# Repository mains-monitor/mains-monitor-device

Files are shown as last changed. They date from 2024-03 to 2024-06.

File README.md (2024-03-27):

# Mains Monitor

The device monitors a presence of mains voltage and sends notifications to the Backend when it turns on or off.
It uses ESP32-C3 MCU as a core component. It implements the logic of the device and connects it to the outer world via Wi-Fi.

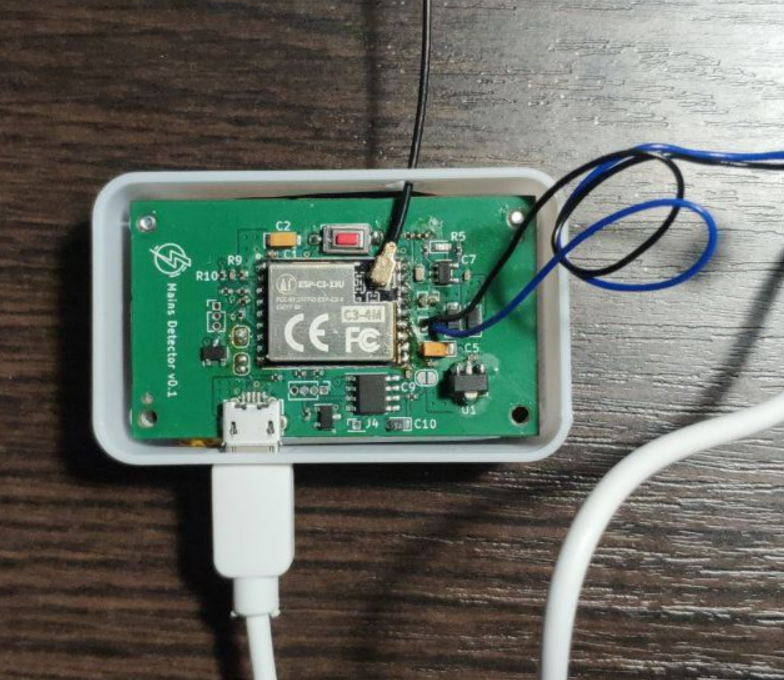
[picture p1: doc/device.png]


The device powers from 5V DC via micro-USB connector and from 3.7V 1000 mAh Li-Po battery, when mains is not available.
Most of the time the device stays in deep sleep mode, so it consumes micro Amps. It wakes up for 20 sec when 5V DC power source becomes available or turns off just for sending a notification to the Backend, then goes to deep sleep again. Peak power consumption when device is transmitting data via Wi-Fi is 500 mA.

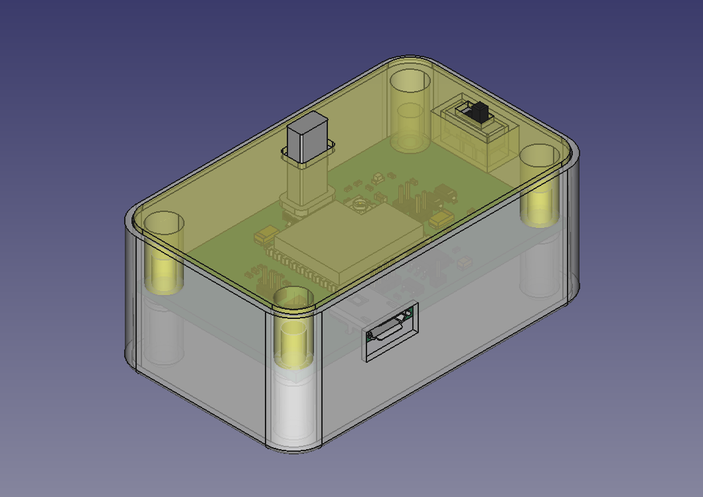
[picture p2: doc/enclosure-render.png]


# First launch configuration

When device starts the first time it creates a Wi-Fi hotspot network with SSID ``MD_<CHIPID>``. The password is ``md123456``.
Connect to it from a smartphone. After that it will open a configuration portal powered by WiFiManager Arduino library. It allows you to select a home Wi-Fi network the device will be connected to and a DTEK group number. The DTEK group number will be used later on the Backend.

# Folders & files description

* ``cad/`` - FreeCAD project and *.STL files of the enclosure for 3D printing
* ``libs/`` - KiCAD library files (schematic symbols and footprints)
* ``production/`` - Gerber, component placement files and Bill Of Materials for PCB production on the factory (for example, JLCPCB)
* ``firmware/`` - firmware sources for ESP32-C3 MCU, the heart of Mains Monitor

# Schematic

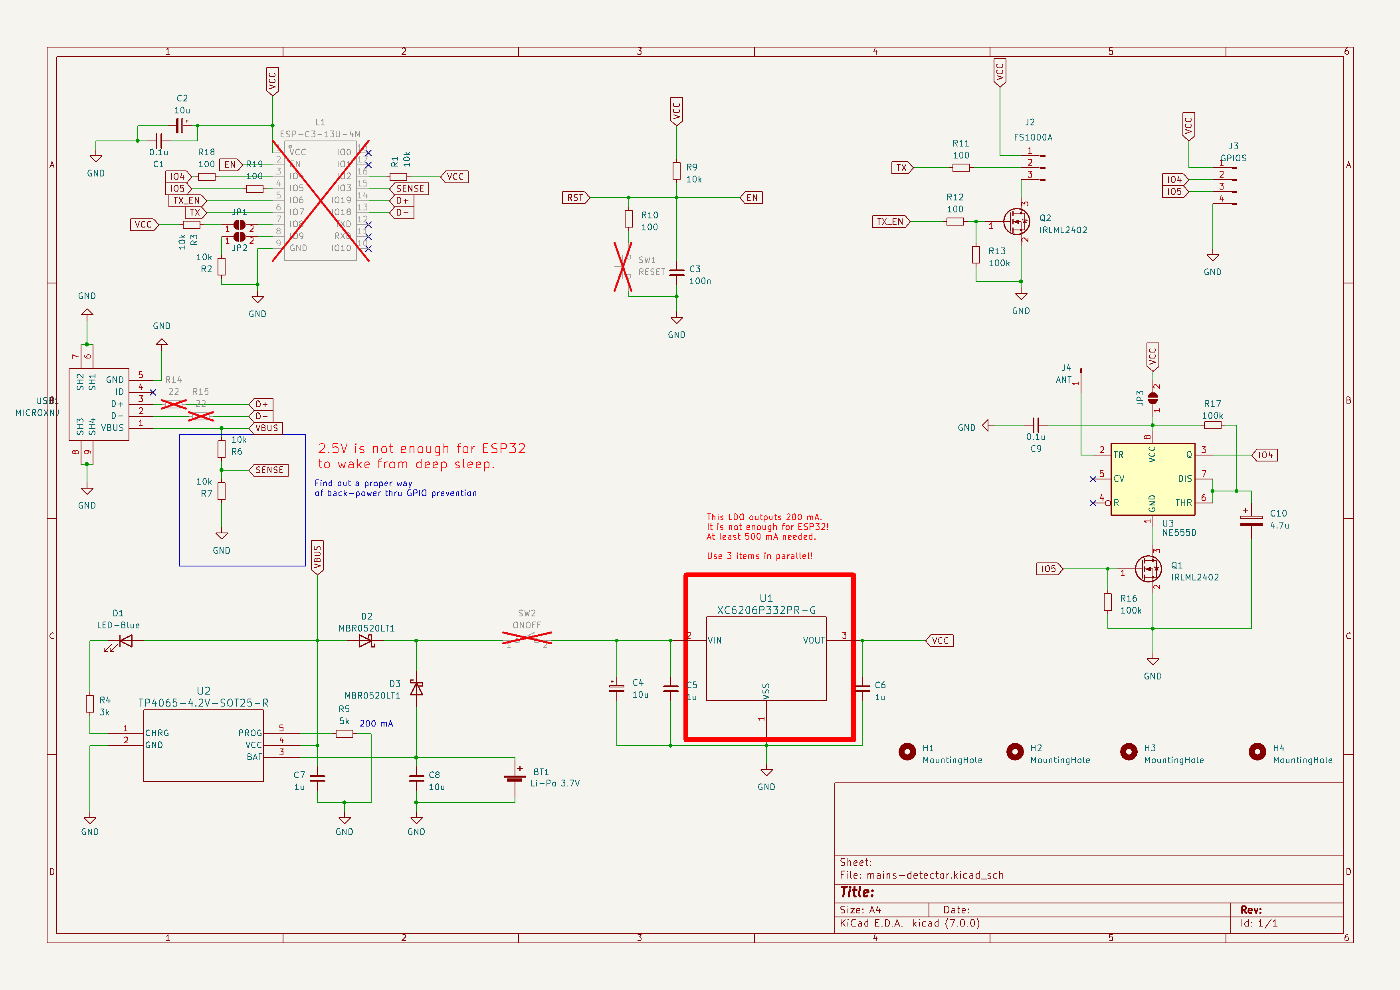
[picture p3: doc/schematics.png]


## PCB design

See [PDF file](doc/pcb-design.pdf) or ``./mains-detector.kicad_pcb`` filer in KiCAD format.

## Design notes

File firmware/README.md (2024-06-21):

# Mains Monitor firmware

* Uses Arduino library
* Uses WiFiManager for first configuration of the device

## How to build and upload firmware

1. Copy and rename ``env.example`` to ``.env``
1. Provide the actual values for environment variables, for example

        MD_API_ENDPOINT_HOST=api.example.server.com
        MD_API_ENDPOINT_PATH=/mains-monitor/set-state
1. Open the project in VSCode with Platformio extension installed and build it
1. Connect the device to a laptop or PC via USB, it will appear as a COM port on Windows
1. Configure Platformio to use that COM port
1. Click "Platformio: Upload" and click reset button on the device to wake it up. Note, the device will be active for 20s and then will disconnect from USB. You have to start flashing it within this interval.

## How to dump nvs partition and read its values on PC

1. Read partition table first, to see where is ``nvs`` partition is located

        esptool -p <COM_PORT OR TTY DEV> read_flash 0x8000 0x1000 part_table.bin

2. Decode partition table with ``gen_esp32part.py``, so you know the partition offset and size of ``nvs``

        python gen_esp32part.py part_table.bin

You should get output like the following:

        Parsing binary partition input...
        Verifying table...
        # ESP-IDF Partition Table
        # Name, Type, SubType, Offset, Size, Flags
        nvs,data,nvs,0x9000,24K,
        phy_init,data,phy,0xf000,4K,
        factory,app,factory,0x10000,1M,
        storage,data,spiffs,0x110000,960K,

3. Read ``nvs`` partition data using ``esptool``

        esptool -p <COM_PORT OR TTY DEV> read_flash 0x9000 0x6000 nvs_readout.bin

``0x6000`` is 24K in HEX

4. Decode ``nvs`` binary

        python analyze_nvs.py nvs_readout.bin -s -b 32

## How to erase ``nvs`` to reset the settings

        python parttool.py -p <COM_PORT OR TTY DEV> erase_partition --partition-name nvs

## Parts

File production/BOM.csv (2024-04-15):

Comment | Designator | Footprint | LCSC
0.1u | C1,C9 | Capacitor_SMD:C_0402_1005Metric | C307331
10u | C2,C4 | Capacitor_Tantalum_SMD:CP_EIA-3216-10_Kemet-I_Pad1.58x1.35mm_HandSolder | C7171
100n | C3 | Capacitor_SMD:C_0402_1005Metric | C307331
1u | C5,C6,C7,C11,C12 | Capacitor_SMD:C_0402_1005Metric | C52923
10u | C8 | Capacitor_SMD:C_0603_1608Metric | C96446
4.7u | C10 | Capacitor_Tantalum_SMD:CP_EIA-2012-12_Kemet-R | C2158112
LED-Blue | D1 | LED_SMD:LED_0603_1608Metric | C2286
MBR0520LT1 | D2,D3 | Diode_SMD:D_SOD-123 | C8598
STATUS | D4 | LED_SMD:LED_0603_1608Metric | C2290
IRLML2402 | Q1,Q2 | Package_TO_SOT_SMD:SOT-23 | C20917
10k | R1,R2,R3,R7,R9 | Resistor_SMD:R_0402_1005Metric | C25744
3k | R4,R8 | Resistor_SMD:R_0402_1005Metric | C25784
5k | R5,R6 | Resistor_SMD:R_0402_1005Metric | C25905
100 | R10,R11,R12,R18,R19 | Resistor_SMD:R_0402_1005Metric | C25076
100k | R13,R16,R17 | Resistor_SMD:R_0402_1005Metric | C25741
XC6206P332PR-G | U1,U4,U5 | footprints:SOT-89_TOR | C526275
TP4065-4.2V-SOT25-R | U2 | footprints1:SOT-23-5L_TPW | C113540
NE555D | U3 | Package_SO:SOIC-8_3.9x4.9mm_P1.27mm | C356725
MICROXNJ | USB1 | kicad_lceda:MICRO-USB-SMD_MICROXNJ | C404969

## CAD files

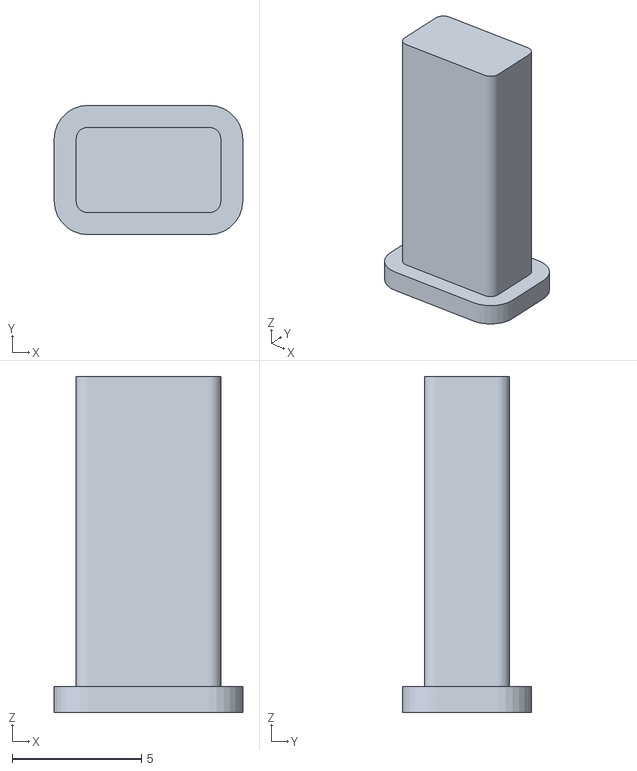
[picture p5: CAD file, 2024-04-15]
cad/enclosure-AssemblyResetButton.stl
7.30 x 5.00 x 13.0

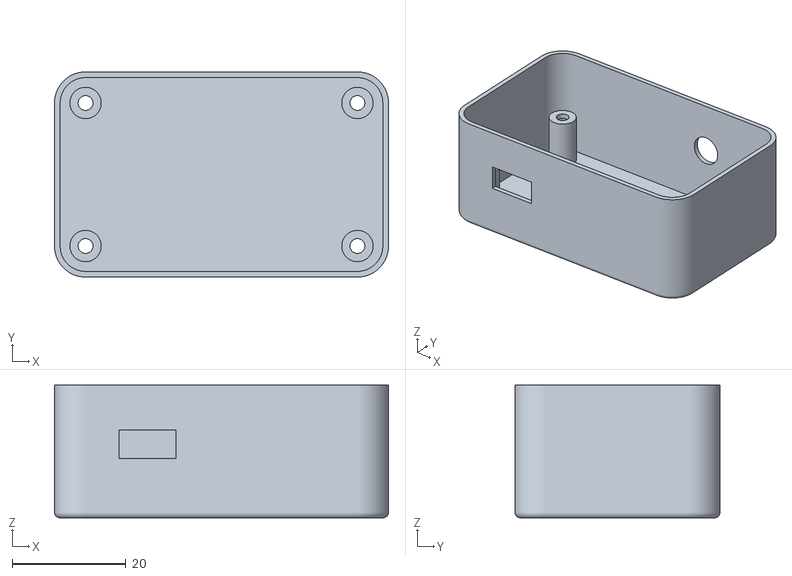
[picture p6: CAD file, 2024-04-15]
cad/enclosure-AssemblyBottomPart.stl
58.6 x 36.0 x 23.3

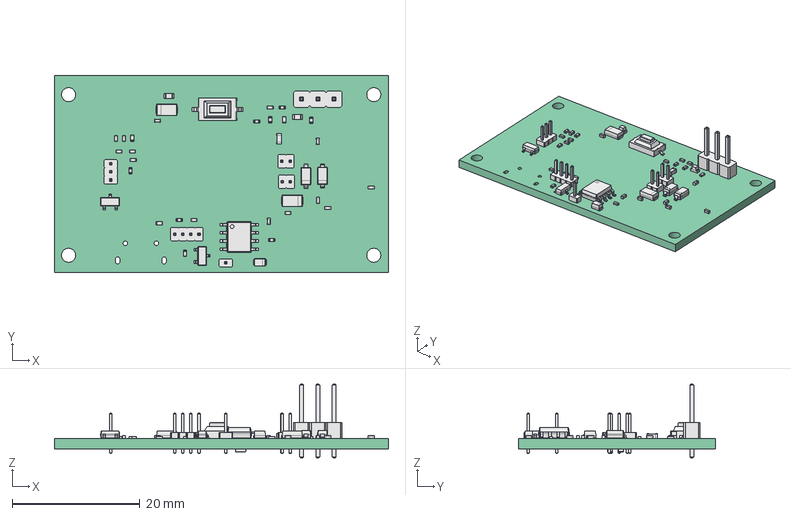
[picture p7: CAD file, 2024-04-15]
cad/mains-detector-tmp.FCStd
52.2 x 30.8 x 11.5 mm
Pcb_dab4
${REFERENCE}_C_0402_1005Metric_null x 8
${REFERENCE}_R_0402_1005Metric_null x 17
${REFERENCE}_PinHeader_1x03_P254mm_Vertical_null
${REFERENCE}_SOIC_8_39x49mm_P127mm_null
${REFERENCE}_LED_0603_1608Metric_null x 2
${REFERENCE}_SOT_23_null x 2
${REFERENCE}_C_0603_1608Metric_null
${REFERENCE}_PinHeader_1x04_P127mm_Vertical_null
${REFERENCE}_PinHeader_1x01_P127mm_Vertical_null
${REFERENCE}_PinHeader_1x03_P127mm_Vertical_null
${REFERENCE}_PinHeader_1x02_P127mm_Vertical_null x 2
${REFERENCE}_CP_EIA_2012_12_Kemet_R_null
${REFERENCE}_CP_EIA_3216_10_Kemet_I_null x 2
${REFERENCE}_D_SOD_123_null x 2
${REFERENCE}_SW_SPST_CK_RS282G05A3_null
${REFERENCE}_R_0603_1608Metric_null x 2

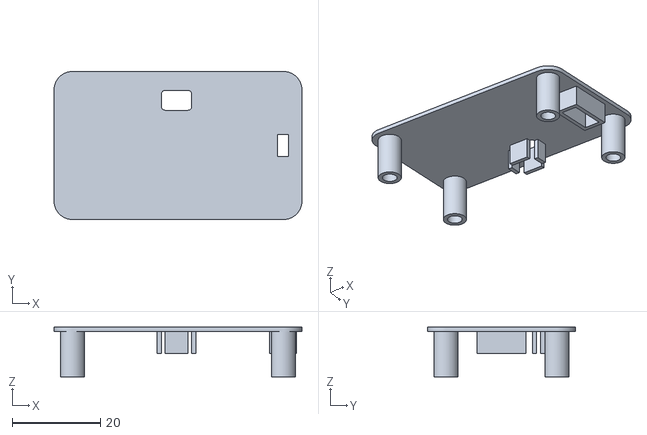
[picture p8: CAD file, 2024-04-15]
cad/enclosure-AssemblyTopPart.stl
56.1 x 33.5 x 11.3

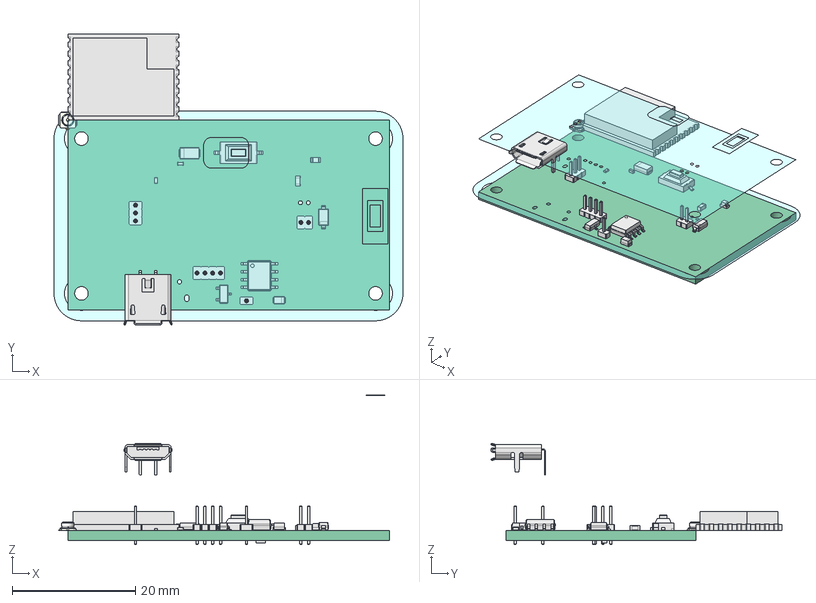
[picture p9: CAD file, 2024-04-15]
cad/enclosure.FCStd
56.6 x 47.3 x 24.2 mm
PinGND
PinSign
PinGND001
Micro USB 2 pin
Pcb_dab4
C1_C_0402_1005Metric_6f217ad45a18
R9_R_0402_1005Metric_7eab74a2859a
U3_SOIC_8_39x49mm_P127mm_bba1476a081f
D1_LED_0603_1608Metric_7d91a2106a29
Q1_SOT_23_2e7f4aaea85a
C8_C_0603_1608Metric_5c3886aaa098
J3_PinHeader_1x04_P127mm_Vertical_1c922c4ce59d
J4_PinHeader_1x01_P127mm_Vertical_20e830154123
J2_PinHeader_1x03_P127mm_Vertical_7fb6fa2eeee2
SW2_PinHeader_1x02_P127mm_Vertical_0a334a59d262
C10_CP_EIA_2012_12_Kemet_R_8c60f9f2d0d4
C2_CP_EIA_3216_10_Kemet_I_f65035e6d3dc
D3_D_SOD_123_7fc438e2cfe4
SW1_SW_SPST_CK_RS282G05A3_fa16e5ecf222
R14_R_0603_1608Metric_df99ae290d1b
_Element
_Element005
_Element006
_Element007
_Element008
_Element009
_Element010

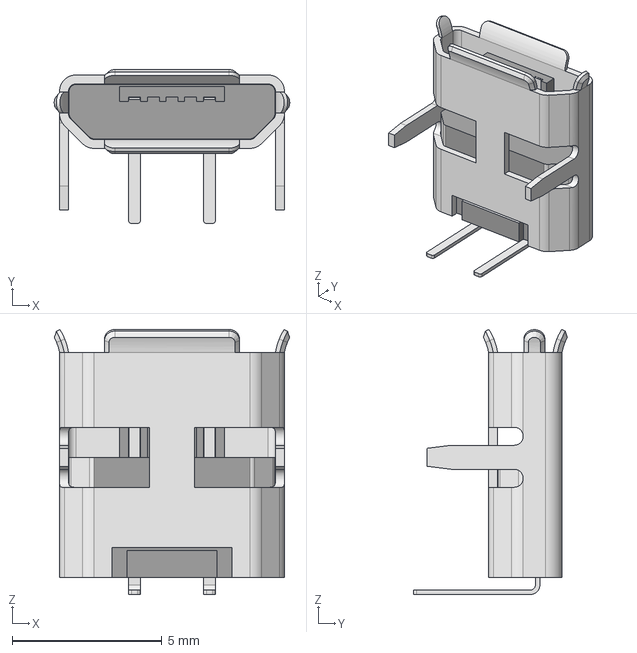
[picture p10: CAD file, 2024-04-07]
cad/Micro USB 2 pin.step
7.85 x 5.13 x 8.83 mm

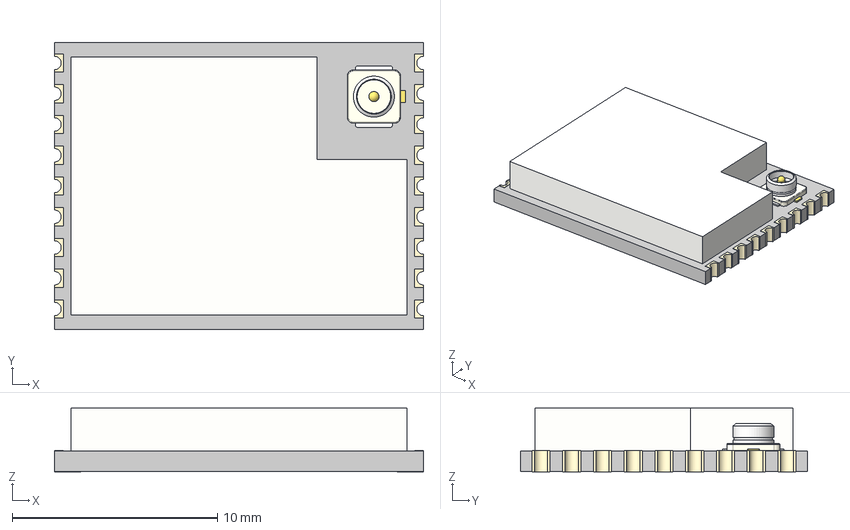
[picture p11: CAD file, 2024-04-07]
cad/ESP32-C3-13U v2.step
18.0 x 14.0 x 3.12 mm
PinGND
PinSign
PinGND001

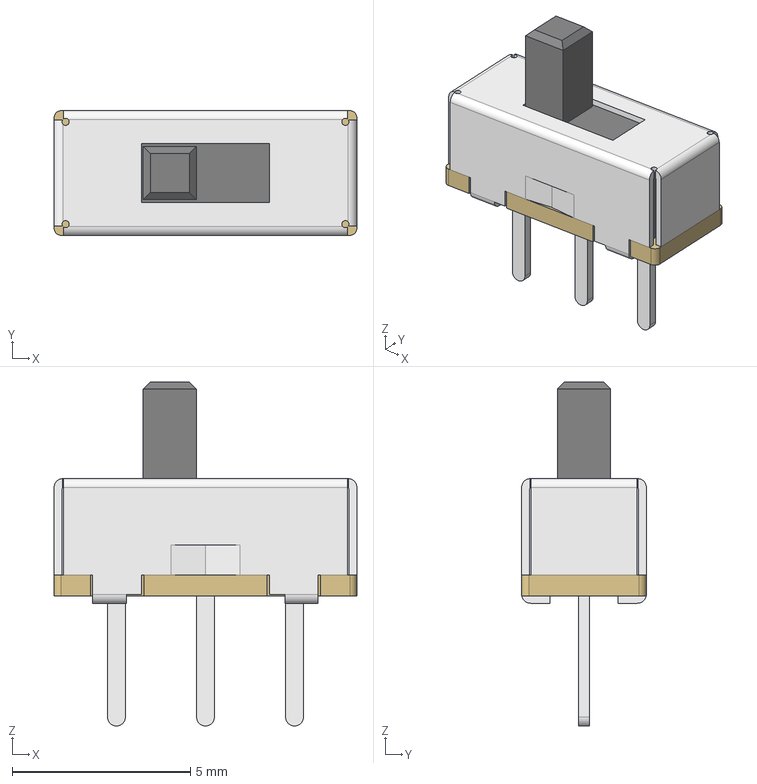
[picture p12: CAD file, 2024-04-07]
cad/SPDT slide switch SS12D00.step
8.50 x 3.50 x 9.66 mm

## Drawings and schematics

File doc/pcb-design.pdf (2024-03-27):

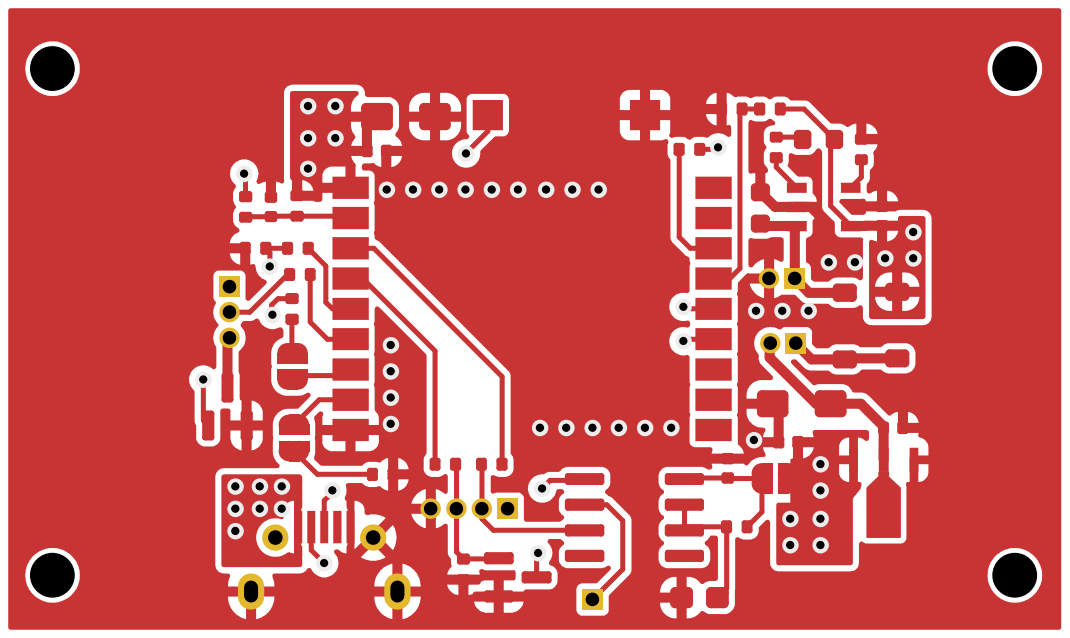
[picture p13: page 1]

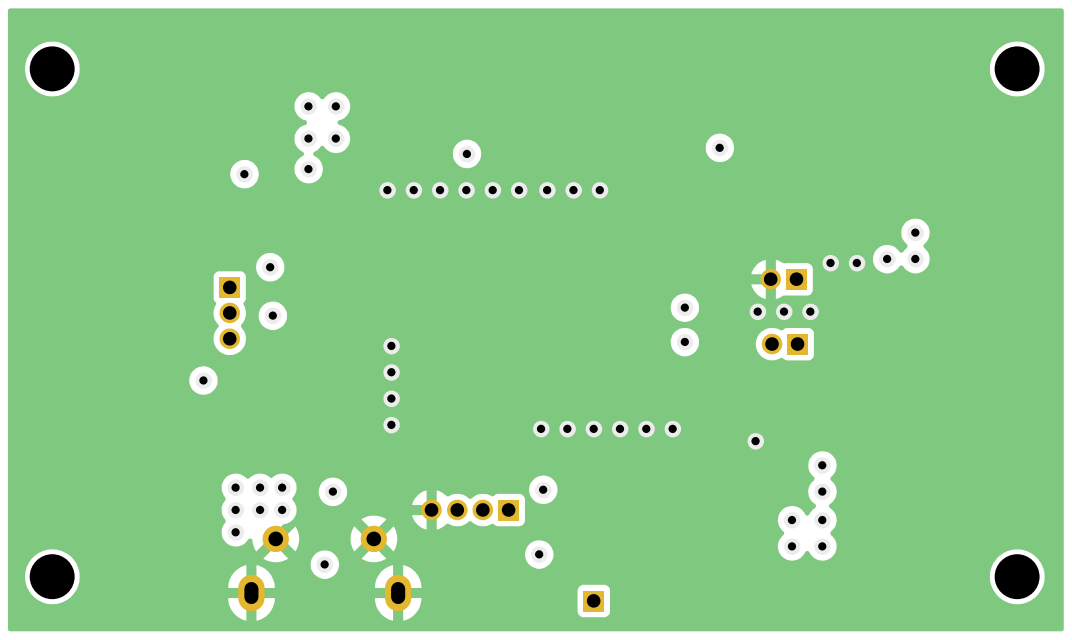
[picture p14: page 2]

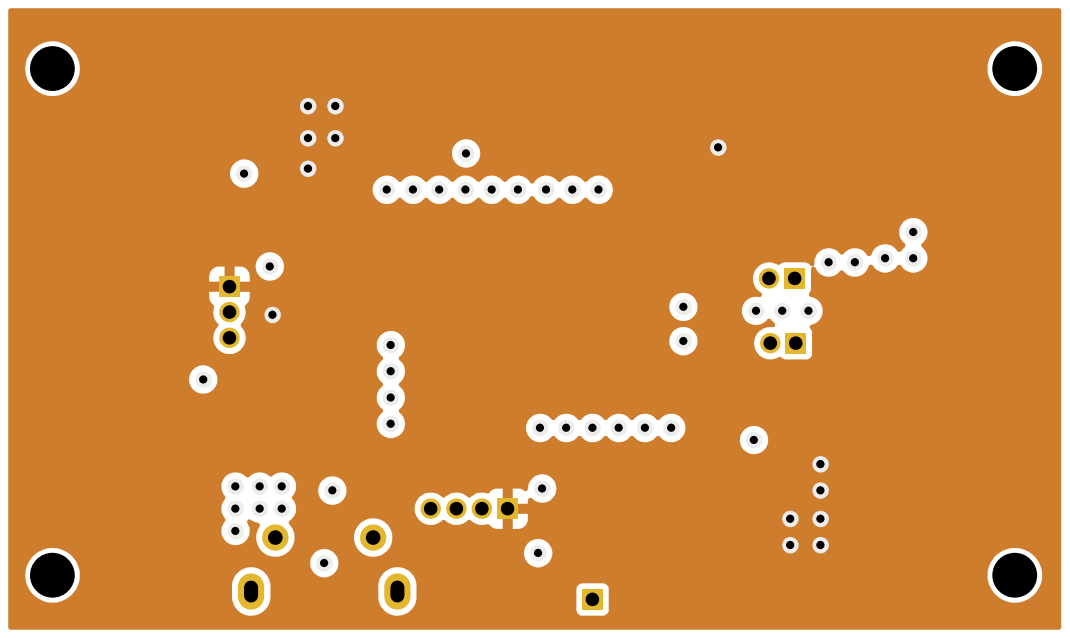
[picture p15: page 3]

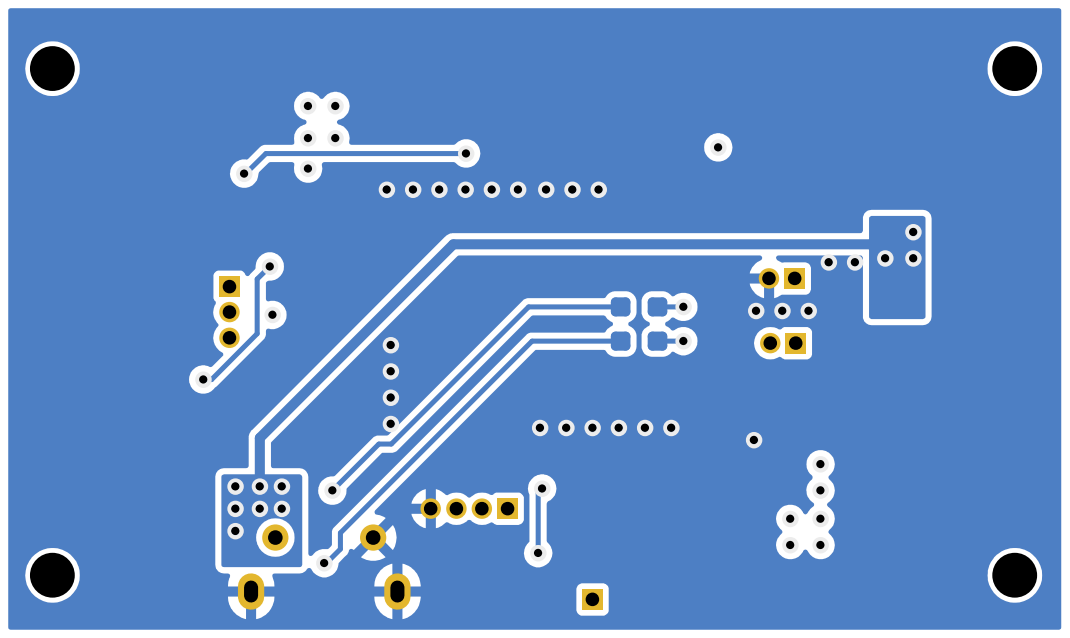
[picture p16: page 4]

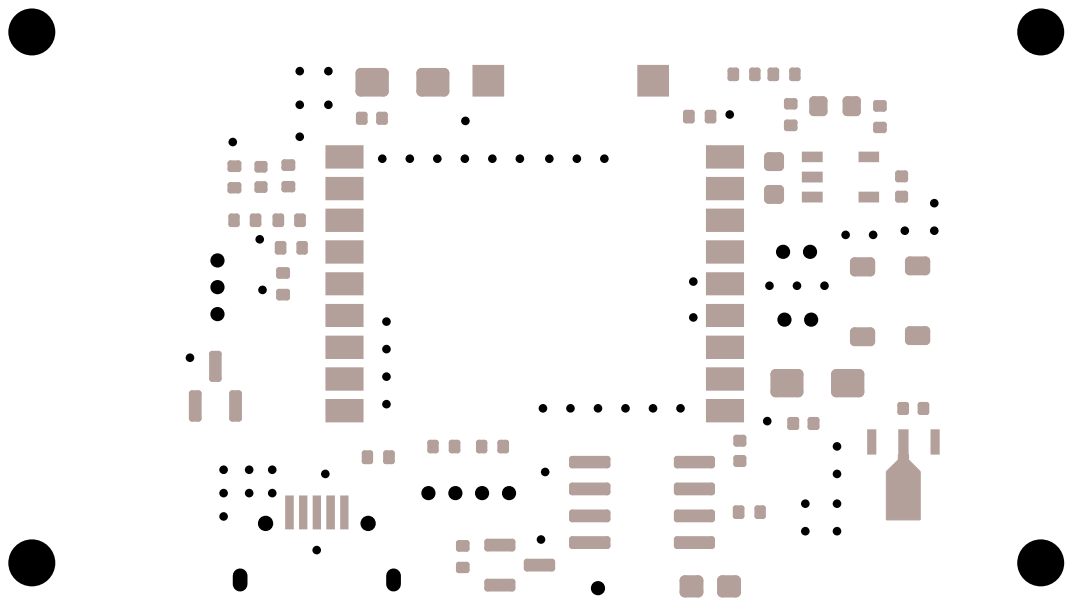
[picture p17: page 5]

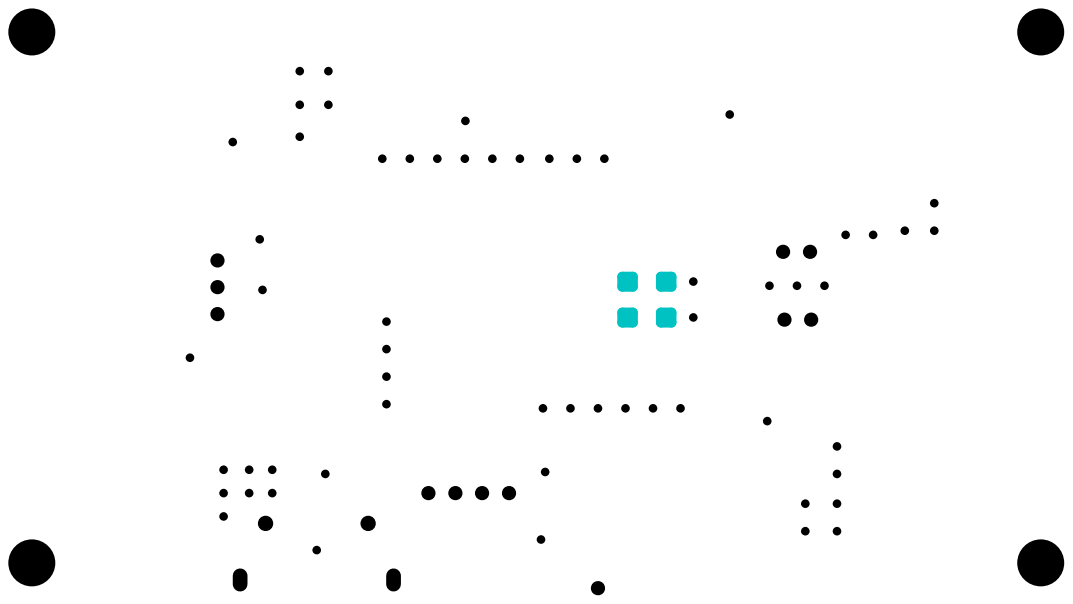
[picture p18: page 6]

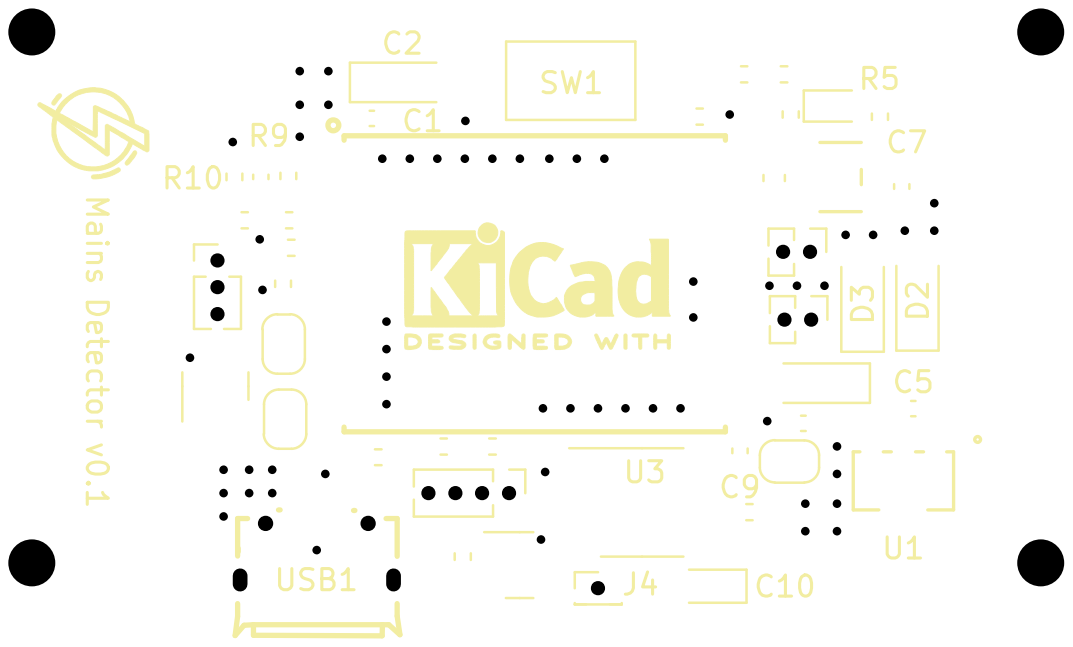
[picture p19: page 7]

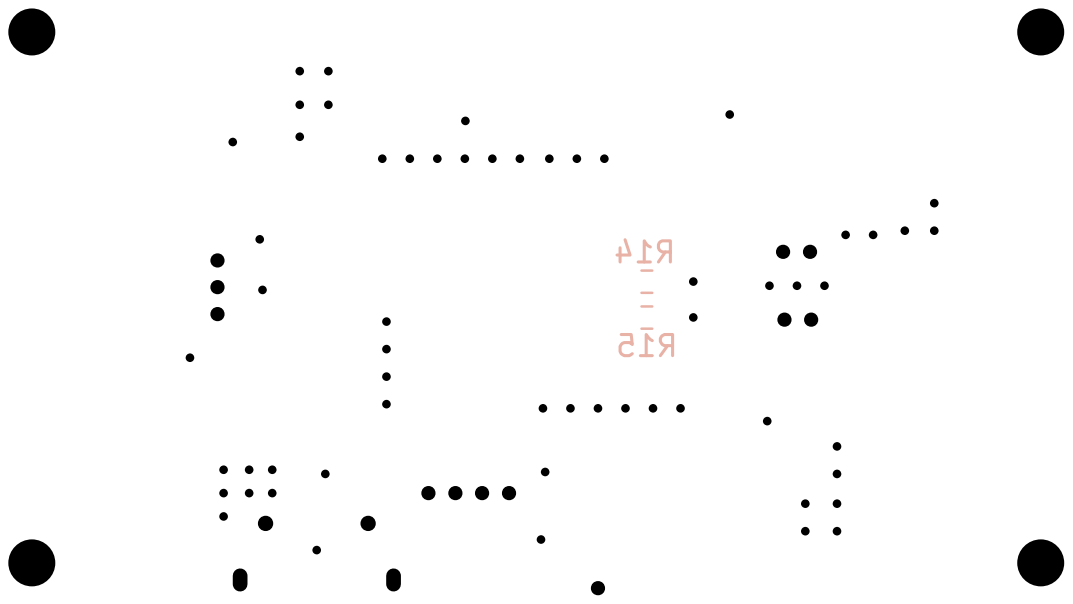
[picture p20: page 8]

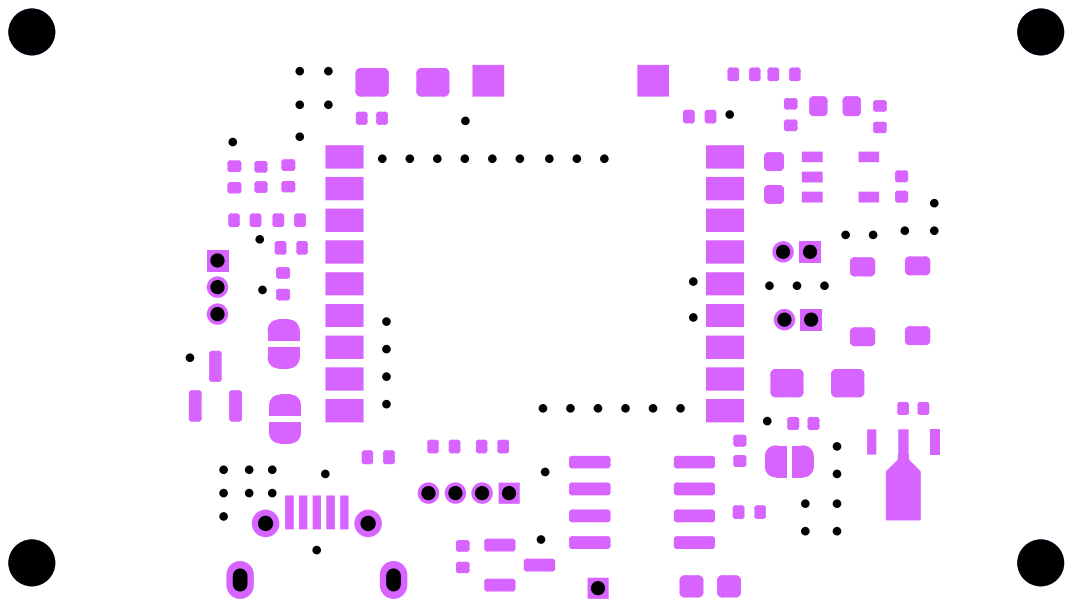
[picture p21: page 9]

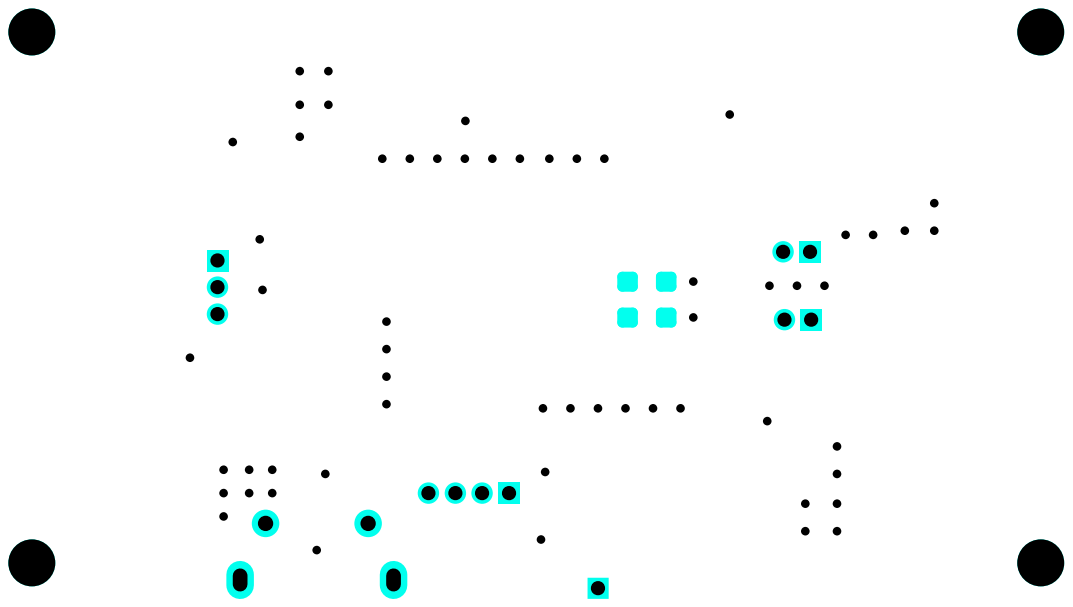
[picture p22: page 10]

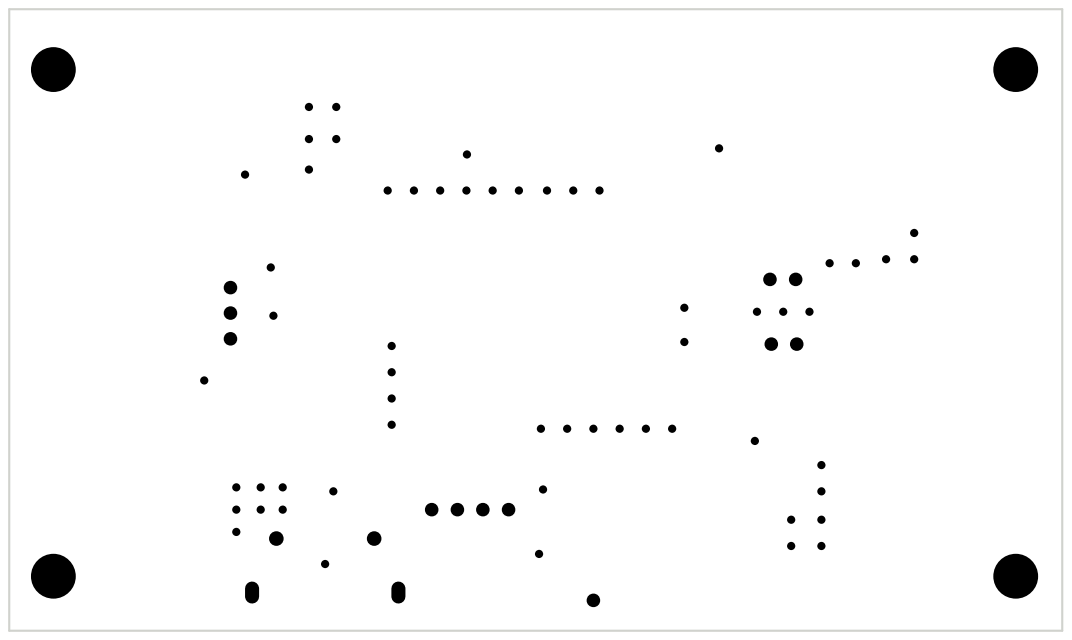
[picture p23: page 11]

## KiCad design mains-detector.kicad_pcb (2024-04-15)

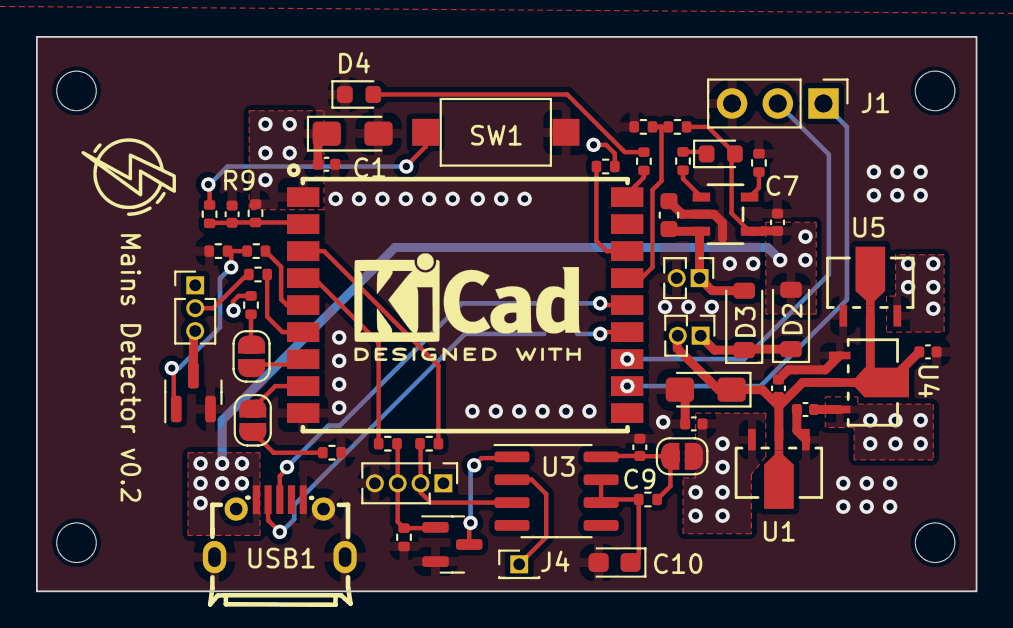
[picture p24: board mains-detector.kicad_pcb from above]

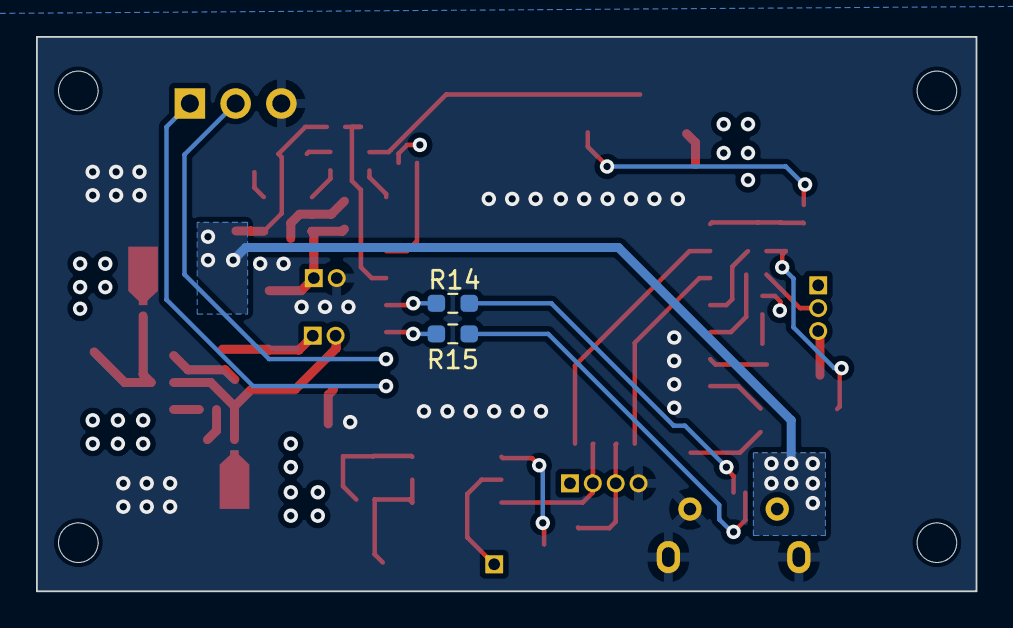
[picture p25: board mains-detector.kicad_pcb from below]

Board: 4 copper layers, 52.2 x 30.8 mm, 58 parts (2 on the bottom side), 38 nets.

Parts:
BT1: Li-Po 3.7V; PinHeader_1x02_P1.27mm_Vertical
C1, C9: 0.1u; C_0402_1005Metric
C2, C4: 10u; CP_EIA-3216-10_Kemet-I_Pad1.58x1.35mm_HandSolder
C3: 100n; C_0402_1005Metric
C5, C6, C7, C11, C12: 1u; C_0402_1005Metric
C8: 10u; C_0603_1608Metric
C10: 4.7u; CP_EIA-2012-12_Kemet-R
D1: LED-Blue; LED_0603_1608Metric
D2, D3: MBR0520LT1; D_SOD-123
D4: STATUS; LED_0603_1608Metric
H1, H2, H3, H4: MountingHole; MountingHole_2.2mm_M2
J1: UART; PinHeader_1x03_P2.54mm_Vertical
J2: FS1000A; PinHeader_1x03_P1.27mm_Vertical
J3: GPIOS; PinHeader_1x04_P1.27mm_Vertical
J4: ANT; PinHeader_1x01_P1.27mm_Vertical
JP1, JP2, JP3: SolderJumper_2_Open; SolderJumper-2_P1.3mm_Open_RoundedPad1.0x1.5mm
L1: ESP-C3-13U-4M; WIRELM-SMD_ESP-C3-13U-2M
Q1, Q2: IRLML2402; SOT-23
R1, R2, R3, R7, R9: 10k; R_0402_1005Metric
R4, R8: 3k; R_0402_1005Metric
R5, R6: 5k; R_0402_1005Metric
R10, R11, R12, R18, R19: 100; R_0402_1005Metric
R13, R16, R17: 100k; R_0402_1005Metric
R14, R15: 22; R_0603_1608Metric_Pad0.98x0.95mm_HandSolder
SW1: RESET; SW_SPST_CK_RS282G05A3
SW2: ONOFF; PinHeader_1x02_P1.27mm_Vertical
U1, U4, U5: XC6206P332PR-G; SOT-89_TOR
U2: TP4065-4.2V-SOT25-R; SOT-23-5L_TPW
U3: NE555D; SOIC-8_3.9x4.9mm_P1.27mm
USB1: MICROXNJ; MICRO-USB-SMD_MICROXNJ

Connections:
D+: L1.14 (IO19), R14.2
D-: L1.13 (IO18), R15.2
EN: C3.1, L1.2 (EN), R9.2, R10.1
GND: BT1.2 (-), C1.1, C2.2, C3.2, C4.2, C5.2, C6.2, C7.2, C8.2, C9.1, C10.2, C11.2, C12.2, D4.1 (K), J1.3, J3.4, L1.9 (GND), Q1.2 (S), Q2.2 (S), R2.2, R5.2, R7.2, R13.1, R16.1, SW1.1, U1.1 (VSS), U2.2 (GND), U4.1 (VSS), U5.1 (VSS), USB1.5 (GND), USB1.6 (SH1), USB1.7 (SH2), USB1.8 (SH3), USB1.9 (SH4)
IO4: J3.2, R18.1, U3.3 (Q)
IO5: J3.3, Q1.1 (G), R16.2, R19.1
unnamed: BT1.1 (+), C8.1, D3.2 (A), U2.3 (BAT)
unnamed: D1.1 (K), R4.2
unnamed: D2.1 (K), D3.1 (K), SW2.1 (A)
unnamed: D4.2 (A), R8.1
unnamed: J1.1, L1.11 (RXD)
unnamed: J1.2, L1.12 (TXD)
unnamed: J2.2, R11.2
unnamed: J2.3, Q2.3 (D)
unnamed: J4.1, U3.2 (TR)
unnamed: JP1.1 (A), R3.2
unnamed: JP1.2 (B), L1.7 (IO8)
unnamed: JP2.1 (A), R2.1
unnamed: JP2.2 (B), L1.8 (IO9)
unnamed: C9.2, JP3.1 (A), R17.2, U3.8 (VCC)
unnamed: L1.18 (IO0), R8.2
unnamed: L1.16 (IO2), R1.2
unnamed: L1.3 (IO4), R18.2
unnamed: L1.4 (IO5), R19.2
unnamed: Q1.3 (D), U3.1 (GND)
unnamed: Q2.1 (G), R12.2, R13.2
unnamed: R10.2, SW1.2
unnamed: C4.1, C5.1, C11.1, SW2.2 (B), U1.2 (VIN), U4.2 (VIN), U5.2 (VIN)
unnamed: R4.1, U2.1 (CHRG)
unnamed: R5.1, U2.5 (PROG)
unnamed: C10.1, R17.1, U3.6 (THR), U3.7 (DIS)
unnamed: R14.1, USB1.3 (D+)
unnamed: R15.1, USB1.2 (D-)
SENSE: L1.15 (IO3), R6.2, R7.1
TX: L1.6 (IO7), R11.1
TX_EN: L1.5 (IO6), R12.1
VBUS: C7.1, D1.2 (A), D2.2 (A), R6.1, U2.4 (VCC), USB1.1 (VBUS)
VCC: C1.2, C2.1, C6.1, C12.1, J2.1, J3.1, JP3.2 (B), L1.1 (VCC), R1.1, R3.1, R9.1, U1.3 (VOUT), U4.3 (VOUT), U5.3 (VOUT)

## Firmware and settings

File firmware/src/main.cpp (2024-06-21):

#include <string.h>
#include <stdlib.h>
#include "freertos/FreeRTOS.h"
#include "freertos/task.h"
#include "esp_log.h"
#include "esp_system.h"
#include "nvs_flash.h"
#include "esp_netif.h"
#include "esp_timer.h"
#include "esp_event.h"
#include "esp_sleep.h"
#include "driver/gpio.h"

#include "config.hpp"
#include "md_config.hpp"
#include "md_wireless.hpp"
#include "md_state_sender.hpp"

#define LED_PIN GPIO_NUM_1
#define SENSE_PIN GPIO_NUM_3

static const char *LOG_TAG = "main";

static const uint64_t WIFI_CONNECTION_TIMEOUT_US = 30000000;  // 30 seconds
static const uint64_t SMART_CONFIG_TIMEOUT_US = 5 * 60000000; // 5 minutes
static const uint32_t CONFIG_BLINK_INTERVAL_MS = 300;
static const uint32_t HTTP_RETRY_INTERVAL_MS = 10000; // 10 seconds
static const uint32_t GO_TO_SLEEP_TIMEOUT_MS = 30000; // 30 seconds
static const uint8_t HTTP_RETRIES_COUNT = 10;
static const uint64_t DEEP_SLEEP_TIMEOUT = 5 * 60 * 1000000; // 5 minutes

static void enter_deep_sleep_wake_on_pin(void)
{
    esp_deepsleep_gpio_wake_up_mode_t mode = gpio_get_level(SENSE_PIN) ? ESP_GPIO_WAKEUP_GPIO_LOW : ESP_GPIO_WAKEUP_GPIO_HIGH;
    ESP_ERROR_CHECK(esp_deep_sleep_enable_gpio_wakeup(1 << SENSE_PIN, mode));
    esp_deep_sleep_start();
}

static void enter_deep_sleep_wake_on_timer(void)
{
    esp_sleep_enable_timer_wakeup(DEEP_SLEEP_TIMEOUT);
    esp_deep_sleep_start();
}

static void app_task(void *param)
{
    static uint8_t retries = 0;
    ESP_LOGI(LOG_TAG, "App task started. Waiting for WiFi connection.");
    while (retries < HTTP_RETRIES_COUNT)
    {
        md_wireless_ensure_connected();
        ESP_LOGI(LOG_TAG, "Trying to send state to BE.");
        bool state = !!gpio_get_level(SENSE_PIN);
        esp_err_t err = md_state_sender_send_state(state);
        if (err != ESP_OK)
        {
            ESP_LOGE(LOG_TAG, "Error sending state: %s", esp_err_to_name(err));
            ESP_LOGI(LOG_TAG, "Retrying in 10 seconds.");
            vTaskDelay(HTTP_RETRY_INTERVAL_MS / portTICK_PERIOD_MS);
            if (state == false)
            {
                // Count retries only if there is no electricity
                retries++;
            }
            continue;
        }
        ESP_LOGI(LOG_TAG, "State sent successfully.");
        break;
    }
    if (retries > 0)
    {
        ESP_LOGW(LOG_TAG, "Failed to send state %d times.Going to sleep for 5 minutes", retries);
        retries = 0;
        enter_deep_sleep_wake_on_timer();
    }
    else
    {
        vTaskDelay(GO_TO_SLEEP_TIMEOUT_MS / portTICK_PERIOD_MS);
    }
    ESP_LOGI(LOG_TAG, "Going to deep sleep.");
    enter_deep_sleep_wake_on_pin();
}

static esp_err_t configure_gpio(void)
{
    gpio_config_t led_io_conf = {};
    led_io_conf.intr_type = GPIO_INTR_DISABLE;
    led_io_conf.mode = GPIO_MODE_OUTPUT;
    led_io_conf.pin_bit_mask = (1ULL << LED_PIN);
    led_io_conf.pull_down_en = GPIO_PULLDOWN_DISABLE;
    led_io_conf.pull_up_en = GPIO_PULLUP_DISABLE;

    ESP_ERROR_CHECK(gpio_config(&led_io_conf));

    gpio_config_t sense_io_conf = {
        .pin_bit_mask = (1ULL << SENSE_PIN),
        .mode = GPIO_MODE_INPUT,
        .pull_up_en = GPIO_PULLUP_DISABLE,
        .pull_down_en = GPIO_PULLDOWN_DISABLE,
        .intr_type = GPIO_INTR_ANYEDGE,
    };

    ESP_ERROR_CHECK(gpio_config(&sense_io_conf));
    return ESP_OK;
}

static md_wireless_config_t wireless_config = {
    .smart_config_key = {0},
    .wifi_connection_timeout_us = WIFI_CONNECTION_TIMEOUT_US,
    .smart_config_timeout_us = SMART_CONFIG_TIMEOUT_US,
    .config_blink_interval_ms = CONFIG_BLINK_INTERVAL_MS,
    .led_gpio = LED_PIN,
    .sense_gpio = SENSE_PIN,
};

extern "C" void app_main()
{
    ESP_ERROR_CHECK(nvs_flash_init());
    ESP_ERROR_CHECK(esp_netif_init());
    ESP_ERROR_CHECK(esp_event_loop_create_default());
    ESP_ERROR_CHECK(configure_gpio());

    md_config_init();
    int8_t smart_config_key[17] = MD_SMARTCONFIG_KEY;
    bzero(wireless_config.smart_config_key, 17);
    memcpy(wireless_config.smart_config_key, smart_config_key, 16);
    md_wireless_init(&wireless_config);
    md_state_sender_init();

    xTaskCreate(app_task, "app_task", 4096, NULL, 3, NULL);
}

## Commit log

2024-04-07 Update CAD and documentation files
    [ESP32-C3-13U v2.step, Micro USB 2 pin.step, SPDT slide switch SS12D00.step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]
2024-04-13 Fix schematic / pcb design gaps, update enclosure
    [BOM.csv, enclosure-AssemblyBottomPart.stl, enclosure-AssemblyResetButton.stl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]
2024-06-21 feat: Add FreeRTOS firmware files and configurations for ESP32-C3
    [partitions.csv]
